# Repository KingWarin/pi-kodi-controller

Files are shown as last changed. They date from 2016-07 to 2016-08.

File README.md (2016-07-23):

# pi-kodi-controller
Fiddling aroung with the pi, kodi and a breadboard

Note:  
    Additionaly the xbmcclient script is needed.  
    This can be found in the [XBMC Repository](https://github.com/xbmc/xbmc)  
    at [xbmcclient](https://github.com/xbmc/xbmc/blob/master/tools/EventClients/lib/python/xbmcclient.py)

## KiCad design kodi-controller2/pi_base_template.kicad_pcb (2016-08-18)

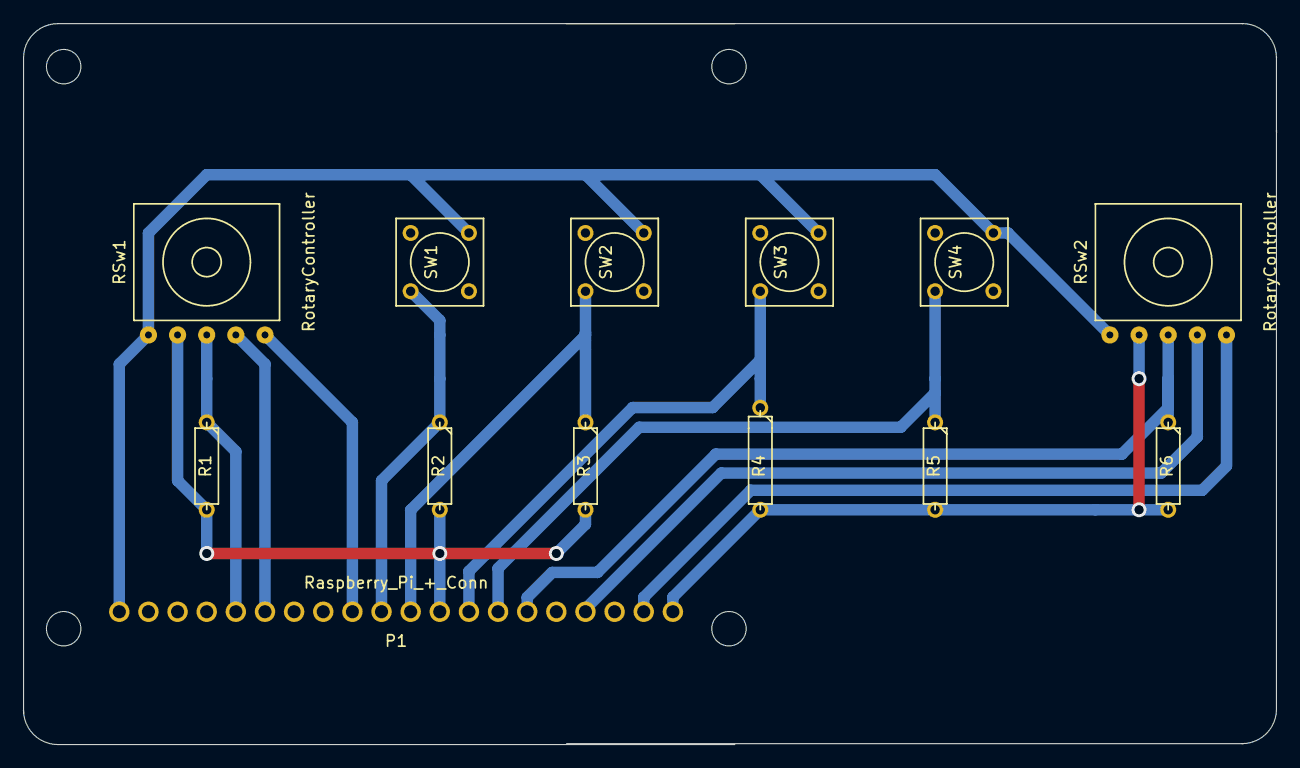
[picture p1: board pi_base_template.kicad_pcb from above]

Board: 2 copper layers, 109.2 x 62.9 mm, 13 parts (0 on the bottom side), 12 nets.

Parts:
P1: Raspberry_Pi_+_Conn; pins
R1, R2, R3, R4, R5, R6: R; R3
RSw1, RSw2: RotaryController; rotaryController
SW1, SW2, SW3, SW4: SW_PUSH_SMALL

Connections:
+3V3: P1.1, P1.9, R1.2, R2.2, R3.2, R4.2, R5.2, R6.2, RSw1.2, RSw2.2
GND: P1.5, P1.13, P1.20, RSw1.1, RSw2.1, SW1.2, SW2.2, SW3.2, SW4.2
unnamed: P1.2, RSw2.5
unnamed: P1.4, RSw2.4
unnamed: P1.6, R6.1, RSw2.3
unnamed: P1.7, R5.1, SW4.1
unnamed: P1.8, R4.1, SW3.1
unnamed: P1.10, R3.1, SW2.1
unnamed: P1.11, R2.1, SW1.1
unnamed: P1.12, RSw1.5
unnamed: P1.15, RSw1.4
unnamed: P1.16, R1.1, RSw1.3

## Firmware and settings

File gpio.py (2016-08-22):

from xbmcclient import *
from socket import *
from controls import RotaryEnc, Button
import RPi.GPIO as GPIO
import time


class CFunctions:
    def __init__(self, direction, sock, addr):
        self.direction = direction
        self.sock = sock
        self.addr = addr
        self.key_map = "KB"

    def _sender(self, button):
        packet = PacketBUTTON(map_name="KB", button_name=button, repeat=0)
        packet.send(self.sock, self.addr)

    def volumeControl(self, direction):
        if direction == self.direction:
            # clockwise -> volume Up
            print "Volume Up"
            self._sender("plus")
        else:
            # counterclockwise -> volume Down
            print "Volume Down"
            self._sender("minus")

    def menuControl(self, direction):
        if direction == self.direction:
            # clockwise -> down
            print "Down"
            self._sender("down")
        else:
            # counterclockwise -> up
            self._sender("up")

    def buttonControl(self):
        print "Switch Volume Direction"
        self.direction = False if self.direction else True

    def playPause(self):
        print "PlayPause"
        self._sender("space")

    def nextTrack(self):
        print "NextTrack"
        self._sender("period")

    def prevTrack(self):
        print "PrevTrack"
        self._sender("comma")

    def levelBack(self):
        print "LevelBack"
        self._sender("backspace")

    def menuSelect(self):
        print "Select"
        self._sender("enter")


def main():
    host = "localhost"
    port = 9777
    addr = (host, port)
    sock = socket(AF_INET,SOCK_DGRAM)

    cf = CFunctions(True, sock, addr)

    # Setup a rotaryEncoder with switch for volume control
    R1 = RotaryEnc(
            PinA=3,
            PinB=7,
            button=11,
            rotaryCallback=cf.volumeControl,
            buttonCallback=cf.buttonControl
         )

    # Setup a rotaryEncoder with switch for menu control
    R2 = RotaryEnc(
            PinA=23,
            PinB=29,
            button=31,
            rotaryCallback=cf.menuControl,
            buttonCallback=cf.menuSelect
         )


    # Setup play/pause button
    B1 = Button(pin=15,callback=cf.playPause)

    # Setup play next button
    B2 = Button(pin=13,callback=cf.nextTrack)

    # Setup play prev button
    B3 = Button(pin=21,callback=cf.prevTrack)

    # Setup one level back button
    B4 = Button(pin=19,callback=cf.levelBack)

    # First packet must be HELO and can contain an icon
    packet = PacketHELO("BreadBoard Control", ICON_NONE)
    packet.send(sock, addr)

    while True:
        #CODE TO CATCH BUTTON PRESS HERE
        R1.read()
        R1.read_button()
        B1.read()
        B2.read()
        B3.read()
        B4.read()
        R2.read()
        R2.read_button()

if __name__ == "__main__":
    main()

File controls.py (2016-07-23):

import RPi.GPIO as GPIO
import time

GPIO.setmode(GPIO.BOARD)
GPIO.setwarnings(False)

class Button:
    ''' Simple Button

    Button needs to know which GPIO-pin it should listen to,
    what to do if it's pressed and can optionally be setup
    so it only triggers once it's pressed or as long as it's
    pressed.
    '''
    def __init__(self,pin,callback,single=True):
        self.pin = pin
        self.callback = callback
        self.oldButton = 1
        self.lastPressed = self.current_millis()
        self.single = single
        GPIO.setup(self.pin, GPIO.IN)

    def current_millis(self):
        return int(round(time.time() * 1000))

    def read(self):
        button = GPIO.input(self.pin)
        now = self.current_millis()
        if self.single:
            if button == False and self.oldButton:
                self.callback()
            self.oldButton = button
        else:
            if button == False and (now - self.lastPressed > 150):
                self.callback()
                self.lastPressed = now

class RotaryEnc:
    ''' RotaryEncoder with integrated switch

    Utilizies the Button-Class for the integrated switch
    Needs to know both GPIO-pins for the rotaryEncoder,
    the GPIO-pin for the swich and callbacks for both the
    encoder and the switch.

    Note: The integrated switch is set to trigger just once it's
    pressed. This is due to the rotaryEncoders I use (KY-040)
    will multi-trigger even with debouncing.
    '''
    def __init__(self,PinA,PinB,button,rotaryCallback,buttonCallback):
        self.PinA = PinA
        self.PinB = PinB
        self.button = Button(button, buttonCallback)
        self.rotaryCallback = rotaryCallback
        self.buttonCallback = buttonCallback
        self.oldPinA = 0
        self.oldButton = 1

        GPIO.setup(self.PinA, GPIO.IN)
        GPIO.setup(self.PinB, GPIO.IN)

    def read(self):
        # function to read the rotary encoder
        pinA = GPIO.input(self.PinA)
        pinB = GPIO.input(self.PinB)

        if pinA and not self.oldPinA:
            if not pinB:
                self.rotaryCallback(True)
            else:
                self.rotaryCallback(False)

        self.oldPinA = pinA

    def read_button(self):
        self.button.read()

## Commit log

2016-07-23 Add single-switch for buttons and comments.
2016-07-25 Switch rotaryController pins / switch direction.
2016-08-05 Added new functions and buttons.
    Well, just added new functions for play/pause, one level back, prev/next
    item and the according buttons to the setup.
    Also adapted the pins for the to-be-produced board for the workshop
    mediacenter.
2016-08-07 Add KiCAD Files for board
    [kodi-controller.kicad_pcb, kodi-controller.sch]
2016-08-10 Add new kodi-controller kicad files.
2016-08-11 Finished new board layout
    [kodi-controller2.kicad_pcb, pi_base_template.kicad_pcb]
2016-08-13 KodeController2: Switched footprint pin positions for push switches.
    [pi_base_template.kicad_pcb]
2016-08-17 Updated clearances.
    [pi_base_template.kicad_pcb]
2016-08-18 Update page settings.
    [pi_base_template.kicad_pcb]
2016-08-20 Adapt pin numbers to meet board layout.
2016-08-21 Switched pins for rotaryEncoders to match direction.
2016-08-22 Removed old circuit board files.
    [kodi-controller.kicad_pcb, kodi-controller.sch]

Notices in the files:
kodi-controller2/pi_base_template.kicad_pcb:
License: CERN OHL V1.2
